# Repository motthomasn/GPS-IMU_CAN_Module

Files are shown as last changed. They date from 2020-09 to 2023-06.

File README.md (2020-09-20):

# GPS-IMU_CAN_Module
Teensy 3.2 based controller board designed to collect GPS &amp; IMU data from SkyTraq Venus838LPx and Bosch BNO055 breakout boards and transmit the data via CAN-Bus

This module was built for my CBR250RRi project. The aim was to have a standalone GPS & IMU module which could send high frequency positional data via CAN-Bus to an ECU or datalogger and therefore improve track performance analysis.

The SkyTraq Venus838LPx breakout board allows GPS data acquisition rates up to 50Hz. The BNO055 breakout board was chosen due to the fact that spatial orientation data was calculated internally. However, the spatial orientation (Euler) angles have proved unreliable so a different sensor or calculation method may need to be looked at.

For further details on the CBR250RRi project, refer to the website https://www.cbr250rri.com/.

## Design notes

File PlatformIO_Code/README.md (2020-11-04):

Code & dependencies provided as PlatformIO project

Note: The current version of the code is configured to output only GPS Lat, Long, Altitude & Speed per Life Racing F88R Basic GPS CAN Recieve. All other data is sent to generic CAN recieve.

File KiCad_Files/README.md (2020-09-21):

This folder contains the KiCad files for the GPS-IMU CAN Module

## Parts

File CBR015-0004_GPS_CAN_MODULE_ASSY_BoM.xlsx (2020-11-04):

Designation | Qty | Description | Value | Manufacturer | Part Number | Package | Supplier | Stock No. / Order Code | Notes | Datasheet
U1 | 1 | Teensy 3.2 |  | PJRC | Teensy 3.2 | PDIP
 | 2 | Teensy Pin Header | 14-way, 2.54mm
 | 2 | Teensy Connector Socket | 14-way, 2.54mm
U2 | 1 | Board Power Regulator | 5V, 1A | Traco Power | TSR 1-2450 | SIP 3 | RS | 666-4379 |  | https://www.tracopower.com/products/tsr1.pdf
U3 | 1 | CAN Transceiver |  | Microchip | MCP2551-I/SN | SOIC 8 | RS | 738-6036 |  | http://ww1.microchip.com/downloads/en/DeviceDoc/21667E.pdf
U4 | 1 | GPS Breakout |  |  | VENUS838FLPx |  |  |  |  | https://www.skytraq.com.tw/products/Venus838FLPx_PB_v1.pdf
 | 2 | GPS Pin Header A | 7-way, 2.54mm
 | 1 | GPS Pin Header B | 6-way, 2.54mm
 | 2 | GPS Connector Socket A | 7-way, 2.54mm
 | 1 | GPS Connector Socket B | 6-way, 2.54mm
 | 2 | GPS Standoff | M3 x 11
 | 4 | GPS Standoff Screw | M3x6
U5 | 1 | IMU |  | Adafruit | BNO055 Breakout | PDIP
 | 1 | IMU Pin Header A | 6-way, 2.54mm
 | 1 | IMU Pin Header B | 4-way, 2.54mm
 | 1 | IMU Connector Socket A | 6-way, 2.54mm
 | 1 | IMU Connector Socket B | 4-way, 2.54mm
 | 4 | IMU Standoff | M2 x 11
 | 8 | IMU Standoff Screw | M2
U6 | 1 | Coin Battery Holder |  | Keystone | 3001 |  | RS | 219-7948 |  | https://www.keyelco.com/product.cfm/product_id/778
C1 | 1 | Power Reg Smoothing Cap | 22µF | Murata | GRM219B30G226ME66D | 0805 | RS | 798-4624
C2 | 1 | CAN Transciever Input Smoothing Cap | 100nF | AVX | 08055C104KAT2A | 0805 | RS | 464-6688
C3 | 1 | Power Reg Output Smoothing Cap | 10nF | AVX | 08055C103KAT2A | 0805 | RS | 464-6672
C4 | 1 | Power Reg Output Smoothing Cap | 10nF | AVX | 08055C103KAT2A | 0805 | RS | 464-6672
C5 | 1 | Power Reg Output Smoothing Cap | 10nF | AVX | 08055C103KAT2A | 0805 | RS | 464-6672
R1 | 1 | CAN Transciever Reset Resistor | 18K | TE Connectivity | CRG0805F18K | 0805 | RS | 223-0590
R2 | 1 | CAN Termination Resistor | 120 | Panasonic | ERJP06F1200V | 0805 | RS | 721-7674
S1 | 1 | CAN Termination Jumper | Single SPST | APEM | IKD0103101 |  | RS | 877-2233 |  | https://www.apem.com/int/ikd-series-168.html
P1 | 1 | Board Connector | 4 Way, 2 Row, Right Angle Pin Header

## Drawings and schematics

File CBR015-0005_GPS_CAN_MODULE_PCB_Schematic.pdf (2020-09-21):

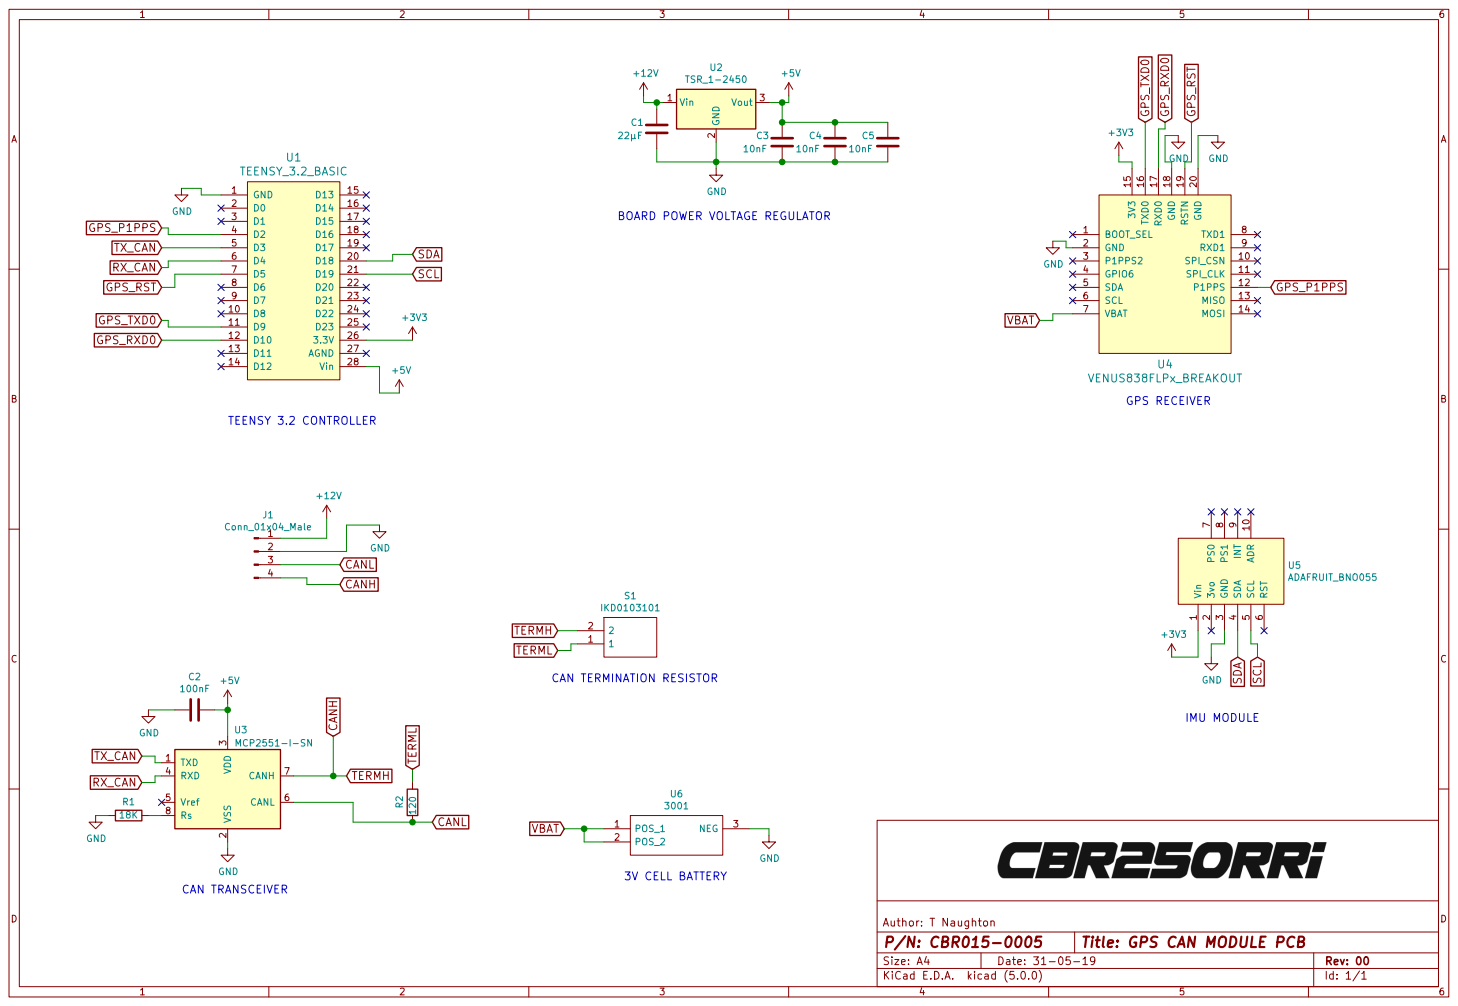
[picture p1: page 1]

BOARD POWER VOLTAGE REGULATOR

3 RXD 4 Vref 5 CANL 6 CANH 7 Rs 8 U3MCP2551-I-SN R2 120R1

Id: 1/1 Title: GPS CAN MODULE PCB

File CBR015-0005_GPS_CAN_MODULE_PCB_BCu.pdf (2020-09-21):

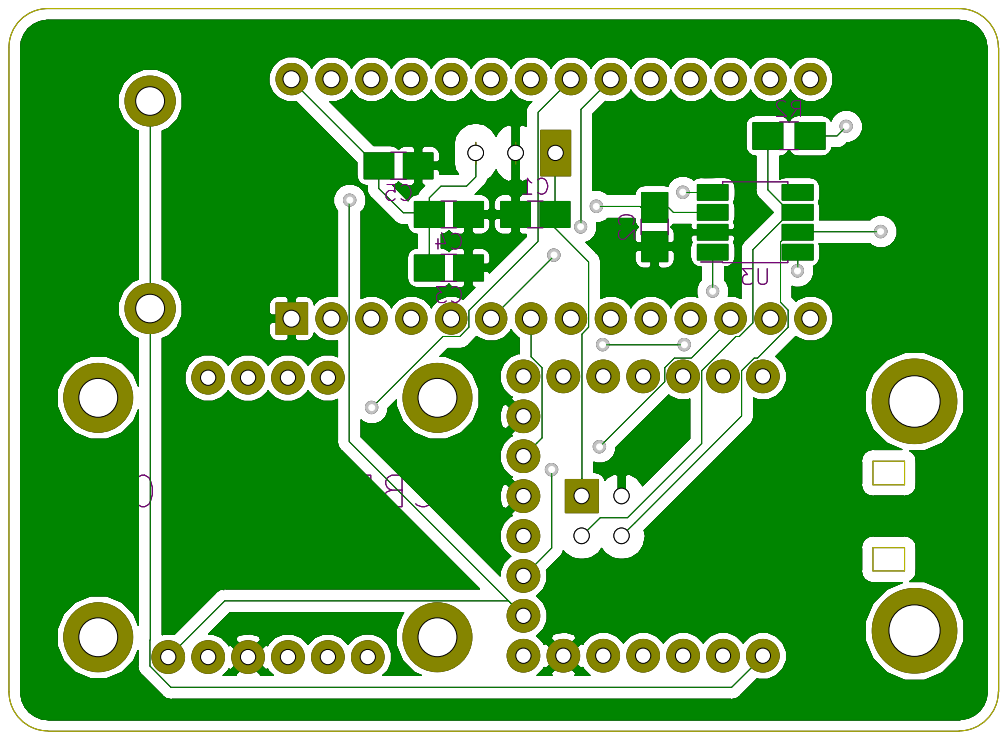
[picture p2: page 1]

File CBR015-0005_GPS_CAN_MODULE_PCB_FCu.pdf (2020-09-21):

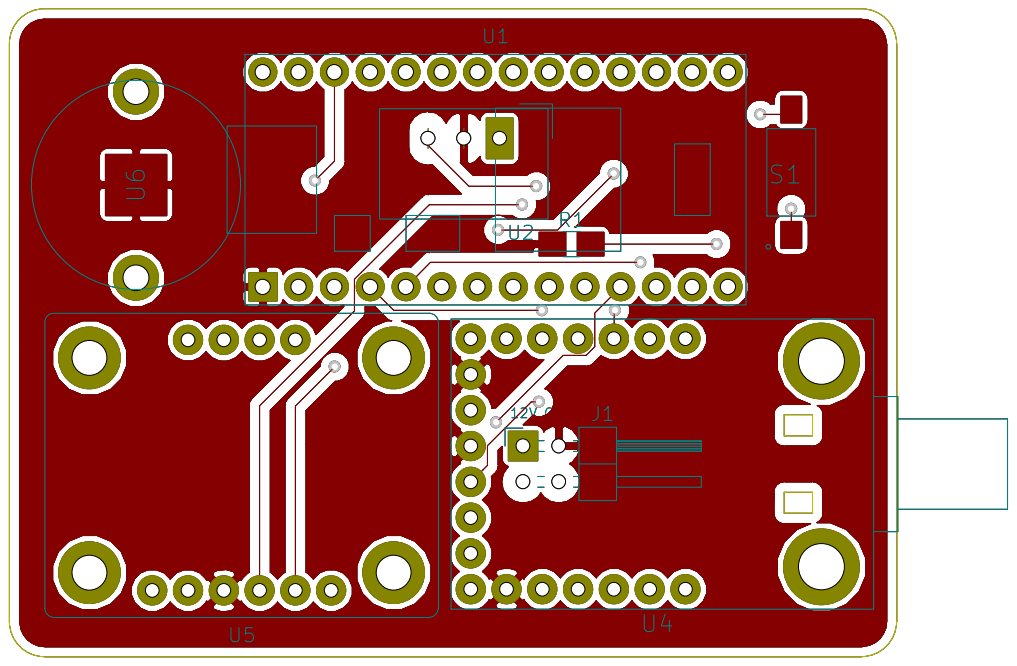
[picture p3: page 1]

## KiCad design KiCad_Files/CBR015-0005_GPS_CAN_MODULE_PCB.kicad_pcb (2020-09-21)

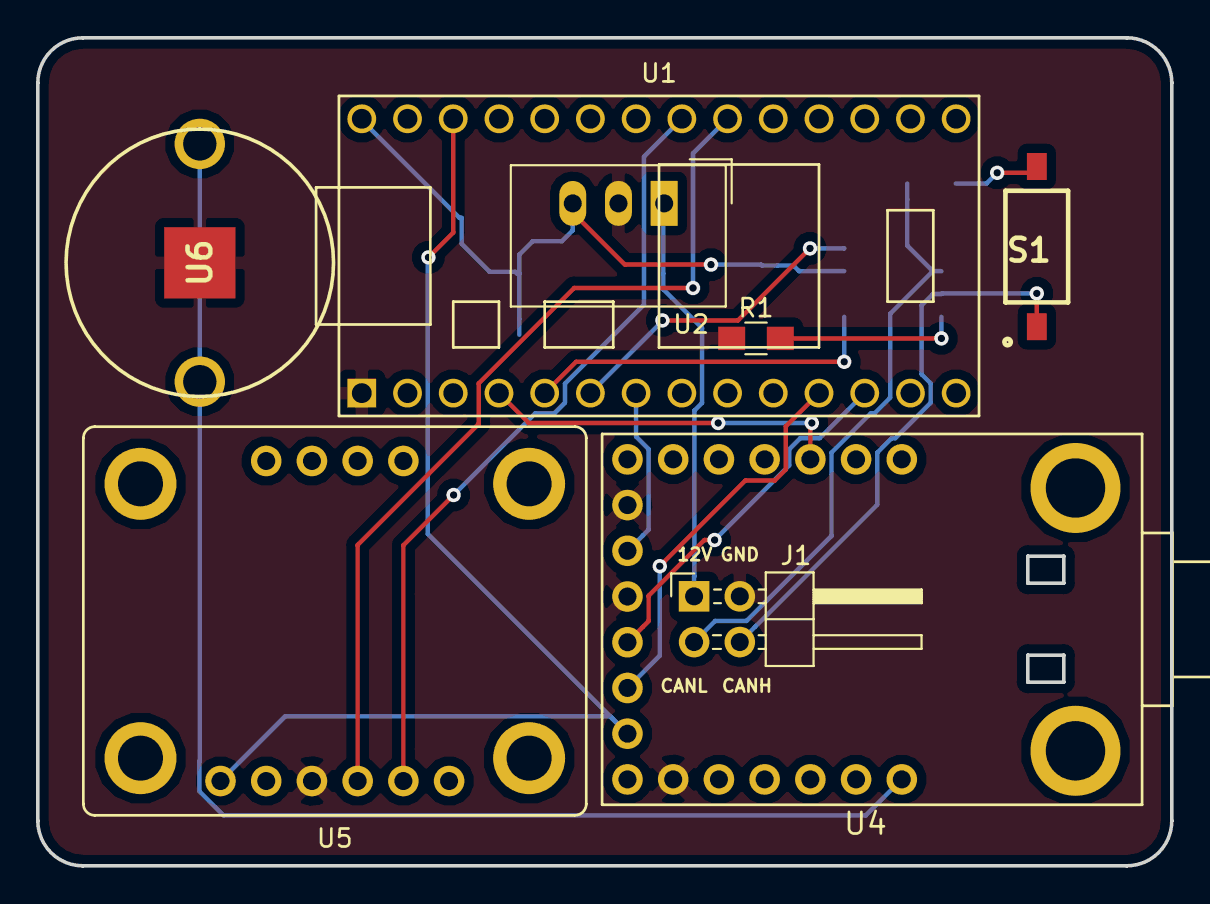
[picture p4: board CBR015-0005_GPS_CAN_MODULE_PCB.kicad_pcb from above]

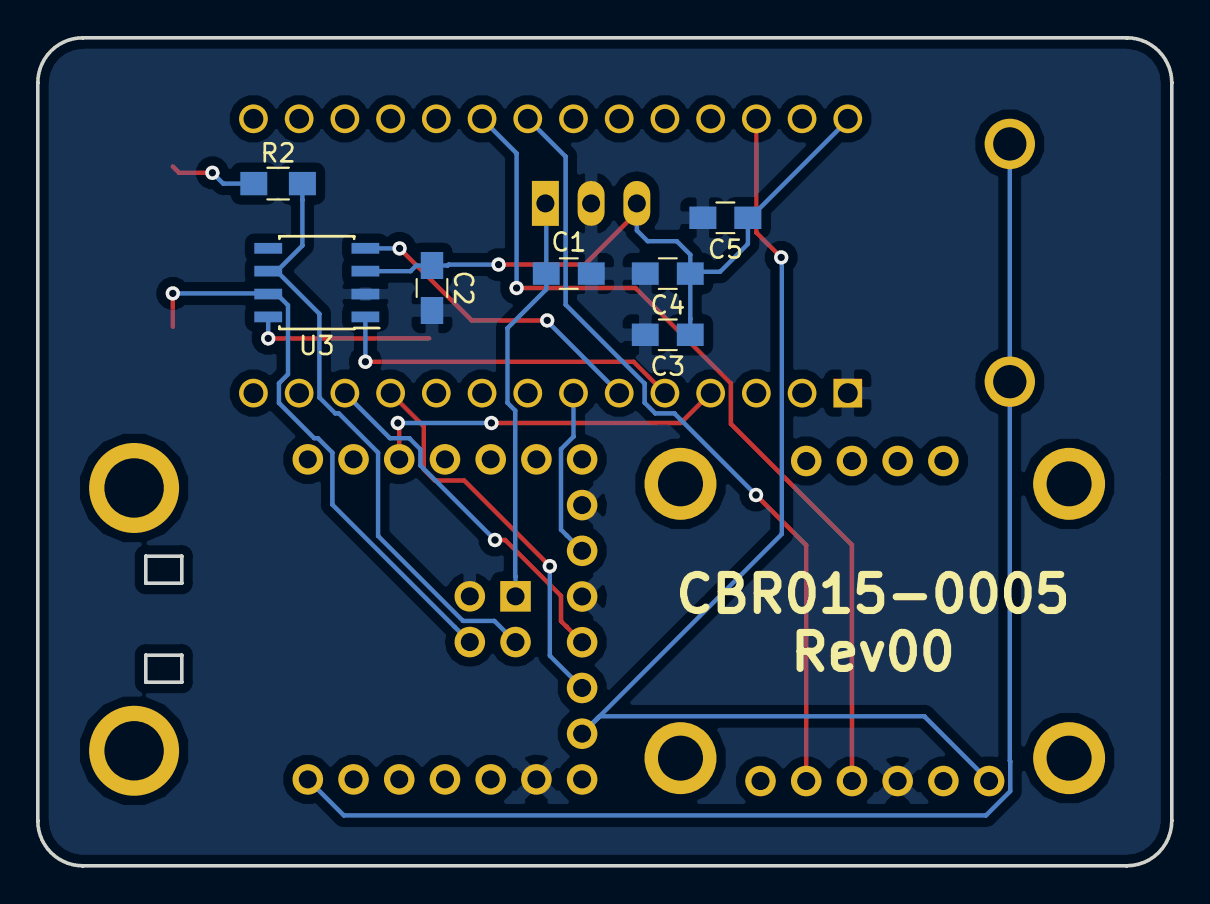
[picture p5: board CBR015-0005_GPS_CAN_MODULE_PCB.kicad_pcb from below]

Board: 2 copper layers, 63.0 x 46.0 mm, 15 parts (7 on the bottom side), 17 nets.

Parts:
C1: 22µF; C_0805_HandSoldering
C2: 100nF; C_0805_HandSoldering
C3, C4, C5: 10nF; C_0805_HandSoldering
J1: Conn_01x04_Male; Pin_Header_Angled_2x02_Pitch2.54mm
R1: 18K; R_0805_HandSoldering
R2: 120; R_0805_HandSoldering
S1: IKD0103101
U1: TEENSY_3.2_BASIC
U2: TSR_1-2450; DCDC-Conv_TRACO_TSR-1
U3: MCP2551-I-SN; SOIC-8_3.9x4.9mm_Pitch1.27mm
U4: VENUS838FLPx_BREAKOUT
U5: ADAFRUIT_BNO055; ADAFRUIT_BNO055_BREAKOUT
U6: 3001

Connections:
+3V3: U1.26, U4.15, U5.1
+5V: C2.1, C3.1, C4.1, C5.1, U1.28, U2.3, U3.3
+12V: C1.1, J1.1, U2.1
CANH: J1.4, S1.1, U3.7
CANL: J1.3, R2.2, U3.6
GND: C1.2, C2.2, C3.2, C4.2, C5.2, J1.2, R1.1, U1.1, U2.2, U3.2, U4.2, U4.18, U4.20, U5.3, U6.3
GPS_P1PPS: U1.4, U4.12
GPS_RST: U1.7, U4.19
GPS_RXD0: U1.12, U4.17
GPS_TXD0: U1.11, U4.16
unnamed: R1.2, U3.8
RX_CAN: U1.6, U3.4
SCL: U1.21, U5.5
SDA: U1.20, U5.4
TERML: R2.1, S1.2
TX_CAN: U1.5, U3.1
VBAT: U4.7, U6.1, U6.2

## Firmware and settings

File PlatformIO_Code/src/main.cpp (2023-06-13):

/*
 * Copyright 2020 THOMAS NAUGHTON
 * 
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
 * The above copyright notice and this permission notice shall be included in all copies or substantial portions of the Software.
 * 
 * THE SOFTWARE IS PROVIDED "AS IS", WITHOUT WARRANTY OF ANY KIND, EXPRESS OR IMPLIED, INCLUDING BUT NOT LIMITED TO THE WARRANTIES OF MERCHANTABILITY, 
 * FITNESS FOR A PARTICULAR PURPOSE AND NONINFRINGEMENT. IN NO EVENT SHALL THE AUTHORS OR COPYRIGHT HOLDERS BE LIABLE FOR ANY CLAIM, DAMAGES OR OTHER LIABILITY, 
 * WHETHER IN AN ACTION OF CONTRACT, TORT OR OTHERWISE, ARISING FROM, OUT OF OR IN CONNECTION WITH THE SOFTWARE OR THE USE OR OTHER DEALINGS IN THE SOFTWARE.
 */

/*
 * CBR015-0004_GPS_CAN_MODULE_ASSY_CODE
 * Version 1.0  02-07-2019      Original code version for Microsquirt based logger config
 * Version 2.0  04-06-2020      Updated code to work with PlatformIO. CAN message IDs & data adjusted to suit F88R GPS data input
 * Version 2.1  15-08-2020      CAN message IDs & data output adjusted to suit F88R basic GPS data input & additional inputs via user defined inputs
 * Version 2.2  12-06-2023      CAN message IDs updated to match CAN config v3.0
 * 
 * This code is designed for use with the CBR015-0004 GPS CAN MODULE ASSY utilising CBR015-0005 Rev00 PCB layout
 * CAN Config:  CBR250RRi_CAN_CONFIG_v3.0.dbc
 * Calibration: CBR250RRi_1.657.1_07-052
 * Messages are sent with MSB First or Big Endian byte order
 * 
 * This code assumes that the GPS breakout board has been preconfigured to the below settings and these settings written to flash memory
 * Baud Rate: 115200
 * Message Type: NMEA
 * Update Rate: 20Hz
 * 
 * See documentation for further details & overview
 * 
 * Comment all serial debug messages from final code. Not useful unless connected to PC 
 */

#include <Arduino.h>

// GPS libraries. All part of NeoGPS library
#include <NMEAGPS.h>
#include <GPSport.h>
#include <Streamers.h>

// IMU libraries
#include <Wire.h>
#include <SPI.h>
#include <Adafruit_Sensor.h>
#include <Adafruit_BNO055.h>  // Adafruit BNO055 library
#include <utility/imumaths.h> // Adafruit BNO055 library

// CAN-Bus Libraries
#include <FlexCAN.h>

//===============================================================================================
// User Config variables
// Define variables most likely to be changed by user
#define baseMsgID 0x200 // CAN message ID for Long/Lat data
#define can_speed 500000 // CAN-Bus baud rate in bps
#define genMsgLen 8      // CAN message size in bytes

//===============================================================================================
// Declare GPS Variables
static NMEAGPS gps; // This object parses received characters into the gps.fix() data structure
static gps_fix fix;
int32_t gpsLongitude, gpsLatitude;
uint16_t gpsHeading;
uint8_t gpsSatellites;
float gpsAltitude, gpsSpeed;

// Declare IMU Variables
Adafruit_BNO055 bno = Adafruit_BNO055(55);
float EulerX, EulerY, EulerZ, GyroX, GyroY, GyroZ, AccelX, AccelY, AccelZ;

// Declare CAN Variables
static CAN_message_t txmsg1, txmsg2, txmsg3, txmsg4;

//===============================================================================================
void GetIMUData()
{
  // Get vector data
  // Euler angles not reliable from BNO055. Code left commented for future re-implementation
  //imu::Vector<3> euler = bno.getVector(Adafruit_BNO055::VECTOR_EULER);         // degrees 0-359.9. Loop time 0.9-1.8ms
  imu::Vector<3> gyro = bno.getVector(Adafruit_BNO055::VECTOR_GYROSCOPE);      // rad/s. Loop time 0.9-1.8ms
  imu::Vector<3> accel = bno.getVector(Adafruit_BNO055::VECTOR_ACCELEROMETER); // m/s^2. Loop time 0.9-1.8ms

  // Separate out vector data
  //EulerX = euler.x();
  //EulerY = euler.y();
  //EulerZ = euler.z();
  GyroX = gyro.x();
  GyroY = gyro.y();
  GyroZ = gyro.z();
  AccelX = accel.x();
  AccelY = accel.y();
  AccelZ = accel.z();
  // time to pass variables, 3-4us
}

//===============================================================================================
void CAN_Send()
{
  // First scale any floats and convert to integers before sending
  int16_t gpsSpeedInt = (gpsSpeed * 10); // convert to kph * 10
  int16_t gpsAltitudeInt = gpsAltitude;  // convert to integer m for F88R
  int16_t gpsHeadingInt = ( gpsHeading * 0.1 );  // convert to signed int & reduce resolution to 0.1deg
  int16_t gpsSatellitesInt = gpsSatellites; // convert to 16 bit signed int for F88R
  //uint16_t EulerXInt = EulerX * 100; // yaw
  //int16_t EulerYInt = EulerY * 100;  // pitch
  //int16_t EulerZInt = EulerZ * 100;  // roll
  int16_t GyroXInt = GyroX * (1800 / PI); // convert from rad/s to deg/s * 10
  int16_t GyroYInt = GyroY * (1800 / PI);
  int16_t GyroZInt = GyroY * (1800 / PI);
  int16_t AccelXInt = (AccelX / 9.81) * 1000; // convert from m/s2 to G * 1000
  int16_t AccelYInt = (AccelY / 9.81) * 1000;
  int16_t AccelZInt = (AccelZ / 9.81) * 1000;
  // time to scale variables, 8-9us

  // Assemble data bytes
  // ID 0x200
  txmsg1.buf[3] = byte(gpsLatitude & 0x000000ffUL);
  txmsg1.buf[2] = byte((gpsLatitude & 0x0000ff00UL) >> 8);
  txmsg1.buf[1] = byte((gpsLatitude & 0x00ff0000UL) >> 16);
  txmsg1.buf[0] = byte((gpsLatitude & 0xff000000UL) >> 24);
  txmsg1.buf[7] = byte(gpsLongitude & 0x000000ffUL);
  txmsg1.buf[6] = byte((gpsLongitude & 0x0000ff00UL) >> 8);
  txmsg1.buf[5] = byte((gpsLongitude & 0x00ff0000UL) >> 16);
  txmsg1.buf[4] = byte((gpsLongitude & 0xff000000UL) >> 24);
  // time to build message, 1us

  // ID 0x201
  txmsg2.buf[1] = byte(gpsSpeedInt & 0x00ffUL);
  txmsg2.buf[0] = byte((gpsSpeedInt & 0xff00UL) >> 8);
  txmsg2.buf[3] = byte(gpsAltitudeInt & 0x00ffUL);
  txmsg2.buf[2] = byte((gpsAltitudeInt & 0xff00UL) >> 8);

  // ID 0x202
  txmsg3.buf[1] = byte(AccelYInt & 0x00ffUL);
  txmsg3.buf[0] = byte((AccelYInt & 0xff00UL) >> 8);
  txmsg3.buf[3] = byte(AccelXInt & 0x00ffUL);
  txmsg3.buf[2] = byte((AccelXInt & 0xff00UL) >> 8);
  txmsg3.buf[5] = byte(AccelZInt & 0x00ffUL);
  txmsg3.buf[4] = byte((AccelZInt & 0xff00UL) >> 8);
  txmsg3.buf[7] = byte(GyroXInt & 0x00ffUL);
  txmsg3.buf[6] = byte((GyroXInt & 0xff00UL) >> 8);

  // ID 0x203
  txmsg4.buf[1] = byte(GyroYInt & 0x00ffUL);
  txmsg4.buf[0] = byte((GyroYInt & 0xff00UL) >> 8);
  txmsg4.buf[3] = byte(GyroZInt & 0x00ffUL);
  txmsg4.buf[2] = byte((GyroZInt & 0xff00UL) >> 8);
  txmsg4.buf[5] = byte(gpsHeadingInt & 0x00ffUL);
  txmsg4.buf[4] = byte((gpsHeadingInt & 0xff00UL) >> 8);
  txmsg4.buf[7] = byte(gpsSatellitesInt & 0x00ffUL);
  txmsg4.buf[6] = byte((gpsSatellitesInt & 0xff00UL) >> 8);
  // time to build all messages, 2-3us

  // Send data
  Can0.write(txmsg1);
  Can0.write(txmsg2);
  Can0.write(txmsg3);
  Can0.write(txmsg4);
  // time to send 1 message, 1-2us. All messages 4-5us
}

/*
//===============================================================================================
void WriteSerial()
{

  // GPS
  Serial.print("Longitude: ");
  Serial.println(float(gpsLongitude / 10000000.0), 7);
  Serial.print("Latitude: ");
  Serial.println(float(gpsLatitude / 10000000.0), 7);
  Serial.print("Altitude: ");
  Serial.println(float(gpsAltitude / 100.0), 2);
  Serial.print("Speed: ");
  Serial.println(gpsSpeed);
  Serial.print("Heading: ");
  Serial.println(float(gpsHeading / 100.0), 2);

  // IMU
  //Serial.print("EulerX: ");
  //Serial.println(EulerX);
  //Serial.print("EulerY: ");
  //Serial.println(EulerY);
  //Serial.print("EulerZ: ");
  //Serial.println(EulerZ);
  //Serial.print("GyroX: ");
  //Serial.println(GyroX);
  //Serial.print("GyroY: ");
  //Serial.println(GyroY);
  //Serial.print("GyroZ: ");
  //Serial.println(GyroZ);
  //Serial.print("AccelX: ");
  //Serial.println(AccelX);
  //Serial.print("AccelY: ");
  //Serial.println(AccelY);
  //Serial.print("AccelZ: ");
  //Serial.println(AccelZ);
}
*/
/*
//===============================================================================================
static void Debug()
{
  // GPS
  while (!DEBUG_PORT);

  DEBUG_PORT.print( F("NMEA.INO: started\n") );
  DEBUG_PORT.print( F("  fix object size = ") );
  DEBUG_PORT.println( sizeof(gps.fix()) );
  DEBUG_PORT.print( F("  gps object size = ") );
  DEBUG_PORT.println( sizeof(gps) );
  DEBUG_PORT.println( F("Looking for GPS device on " GPS_PORT_NAME) );

  //#ifndef NMEAGPS_RECOGNIZE_ALL
  //  #error You must define NMEAGPS_RECOGNIZE_ALL in NMEAGPS_cfg.h!
  //#endif

  #ifdef NMEAGPS_INTERRUPT_PROCESSING
    #error You must *NOT* define NMEAGPS_INTERRUPT_PROCESSING in NMEAGPS_cfg.h!
  #endif

  #if !defined( NMEAGPS_PARSE_GGA ) & !defined( NMEAGPS_PARSE_GLL ) & \
      !defined( NMEAGPS_PARSE_GSA ) & !defined( NMEAGPS_PARSE_GSV ) & \
      !defined( NMEAGPS_PARSE_RMC ) & !defined( NMEAGPS_PARSE_VTG ) & \
      !defined( NMEAGPS_PARSE_ZDA ) & !defined( NMEAGPS_PARSE_GST )

    DEBUG_PORT.println( F("\nWARNING: No NMEA sentences are enabled: no fix data will be displayed.") );

  #else
    if (gps.merging == NMEAGPS::NO_MERGING) {
      DEBUG_PORT.print  ( F("\nWARNING: displaying data from ") );
      DEBUG_PORT.print  ( gps.string_for( LAST_SENTENCE_IN_INTERVAL ) );
      DEBUG_PORT.print  ( F(" sentences ONLY, and only if ") );
      DEBUG_PORT.print  ( gps.string_for( LAST_SENTENCE_IN_INTERVAL ) );
      DEBUG_PORT.println( F(" is enabled.\n"
                            "  Other sentences may be parsed, but their data will not be displayed.") );
    }
  #endif

  DEBUG_PORT.print  ( F("\nGPS quiet time is assumed to begin after a ") );
  DEBUG_PORT.print  ( gps.string_for( LAST_SENTENCE_IN_INTERVAL ) );
  DEBUG_PORT.println( F(" sentence is received.\n"
                        "  You should confirm this with NMEAorder.ino\n") );

  trace_header( DEBUG_PORT );
  DEBUG_PORT.flush();

  // IMU
  if (!bno.begin())
  {
    // There was a problem detecting the BNO055 ... check your connections
    Serial.print("Ooops, no BNO055 detected ... Check your wiring or I2C ADDR!");
    while (1);
  }
}
//*/

//===============================================================================================
//  This is the main GPS parsing loop.
void GPSloop()
{
  while (gps.available(gpsPort))
  {
    fix = gps.read();                // execution time 3-4us
    gpsLongitude = fix.longitudeL(); // integer degrees scaled by 10,000,000
    gpsLatitude = fix.latitudeL();   // integer degrees scaled by 10,000,000
    gpsAltitude = fix.altitude();    // floating point m
    gpsSpeed = fix.speed_kph();      // floating point kph
    gpsHeading = fix.heading_cd();   // integer hundredths of a degree
    gpsSatellites = fix.satellites;  // number of satellites
    // time to pass variables, 3-4us

    // Call any other function after GPS data recieved
    GetIMUData(); // as IMU data can be polled at any time, get the data at the same rate as GPS data is recieved. Loop time average c.4ms?? 2.75ms min
    CAN_Send();   // Loop time 13-14us
    //WriteSerial(); // Use this function to write debug data to serial if possible
  }

} // GPSloop

//===============================================================================================
void setup()
{
  // Setup GPS
  //DEBUG_PORT.begin(115200); // opens standard serial port for PC comms. Disable in final code
  //Serial.begin(115200);

  gpsPort.begin(115200);

  // Setup IMU
  bno.begin();

  // Setup CAN
  Can0.begin(can_speed);

  // Define CAN IDs here
  txmsg1.id = baseMsgID;
  txmsg2.id = (baseMsgID + 1);
  txmsg3.id = (baseMsgID + 2);
  txmsg4.id = (baseMsgID + 3);

  txmsg1.len = genMsgLen;
  txmsg2.len = genMsgLen;
  txmsg3.len = genMsgLen;
  txmsg4.len = genMsgLen;

  //Debug(); // all debug messages moved to a separate function for cleanliness

  delay(500); // delay before entering loop to give GPS a chance to get a fix
}

//===============================================================================================
void loop()
{

  // check if GPS messages are available on each loop. Simply using a timer does not work
  GPSloop(); // Loop time 4ms average, 6ms max when GPS available. 1-2us if not available
}
